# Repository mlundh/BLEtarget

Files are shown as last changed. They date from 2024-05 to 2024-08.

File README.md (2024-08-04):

# BLEtarget 
BLEtarget is an optical electronic scoring target with bluetooth connectivity developed for air guns. 

The project consists of both Hardware and firmware. The source is found in hw and fw respectively. 

## HW
The HW is developed in KiCad 7.0. It consists of a sensor array with support electronics as well as an STM32 with BLE capabilites. 

### Known bugs
BOM error - U8-U10 MCP604 populated with MCP6044 with 14kHz bandwidth, should be MCP604 with 2.8Mhz bandwidth.
BOM error - c32 and corresponding 10u caps should be changed to 10000PF for a shorter signal pulse.
Schematic error - add a jumper to select master/slave. 
Schematic update - add a small memory, fram.

## FW
The firmware developed in CubeIDE.

## SW
The user interface is called Bullseye and developed in Qt using widgets.

### Dependencies
qt6-base-dev-tools
qt6-serialport-dev
cmake

### Raspberry pi Zero 2W with Hyperpixel 4.0 Square
#### Increase swap file:
Edit /etc/dphys-swapfile to change CONF_SWAPSIZE=100 to CONF_SWAPSIZE=2048. After making the change, restart the Pi.
#### Enable Hyperpixel
Add one line in /boot/firmware/config.txt:
dtoverlay=vc4-kms-dpi-hyperpixel4sq
#### Convenience
Enable one-click open of files: 
In Accessories select File Manager
In File Manage select Preference.
Select "Open Files with One Click"
#### Add desktop shortcut
Add desktop shortcut by draging the application to the desktop. Also drag the updateBullseye.sh script to the desktop.

#### Start at bootup

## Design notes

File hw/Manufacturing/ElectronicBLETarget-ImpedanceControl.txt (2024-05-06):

Impedance control required

1) 50 Ohms (+-10%) Single-ended Microstrip
L1 (ref L2)
Trace width = 0.19mm

2) 90 Ohms (+-10%) Differential Microstrip (50 Ohms +-10% Single-Ended))
L1 (ref L2)
Trace width = 0.22mm
Trace spacing = 0.15mm

Confirm trace widths and spacing. Adjust stack-up as necessary.

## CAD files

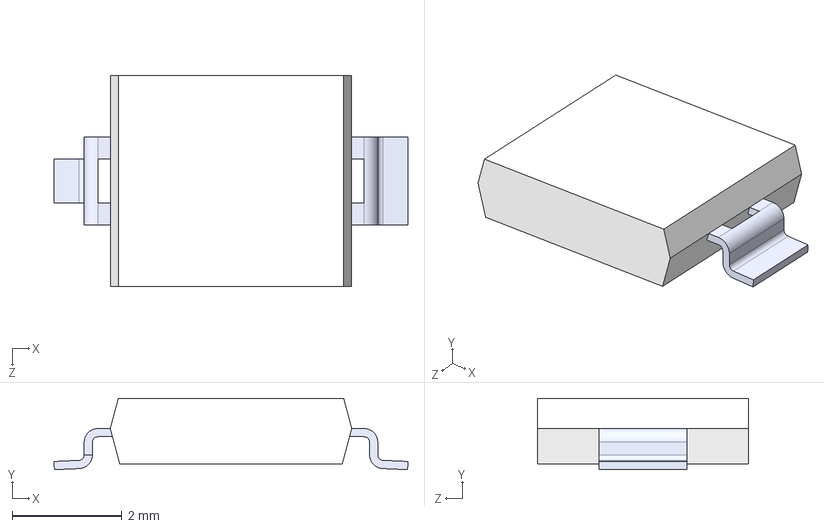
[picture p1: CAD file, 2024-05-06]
hw/BPW_34_S-Z.step
6.45 x 1.30 x 3.85 mm

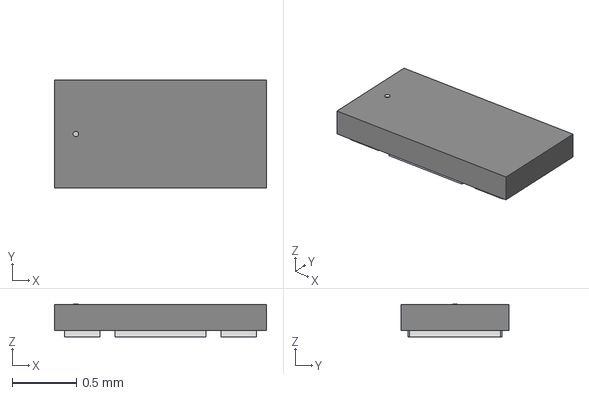
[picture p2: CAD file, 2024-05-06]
hw/DLF-4_1P6X0P8.step
1.65 x 0.838 x 0.257 mm

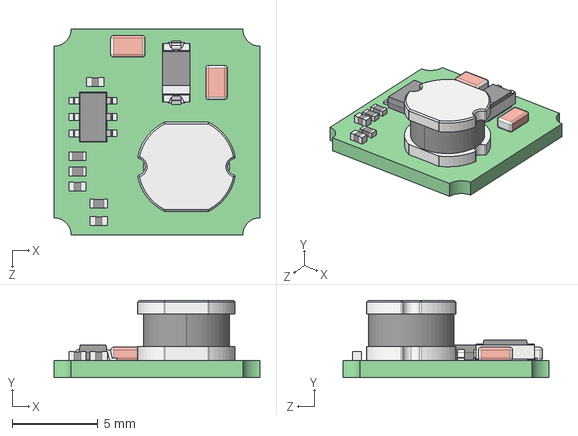
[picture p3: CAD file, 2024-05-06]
hw/CUI_PXO7809-500-M-TR.step
12.0 x 4.50 x 12.0 mm

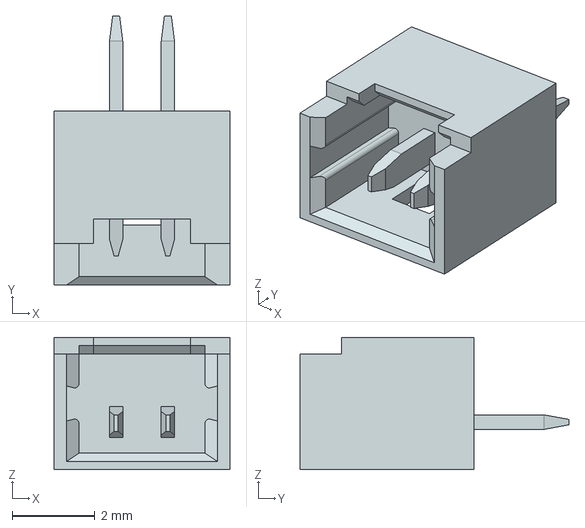
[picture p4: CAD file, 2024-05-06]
hw/530470210.stp
4.25 x 6.50 x 3.20 mm

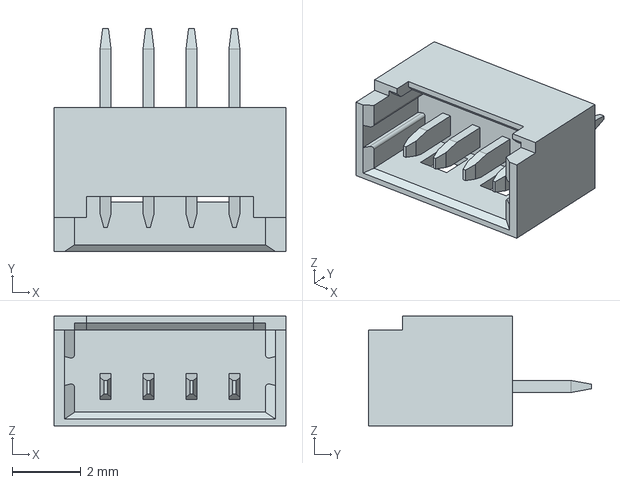
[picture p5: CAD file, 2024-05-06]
hw/530470410.stp
6.75 x 6.50 x 3.20 mm

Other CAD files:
hw/CUI_PXO7805-500-M-TR.step

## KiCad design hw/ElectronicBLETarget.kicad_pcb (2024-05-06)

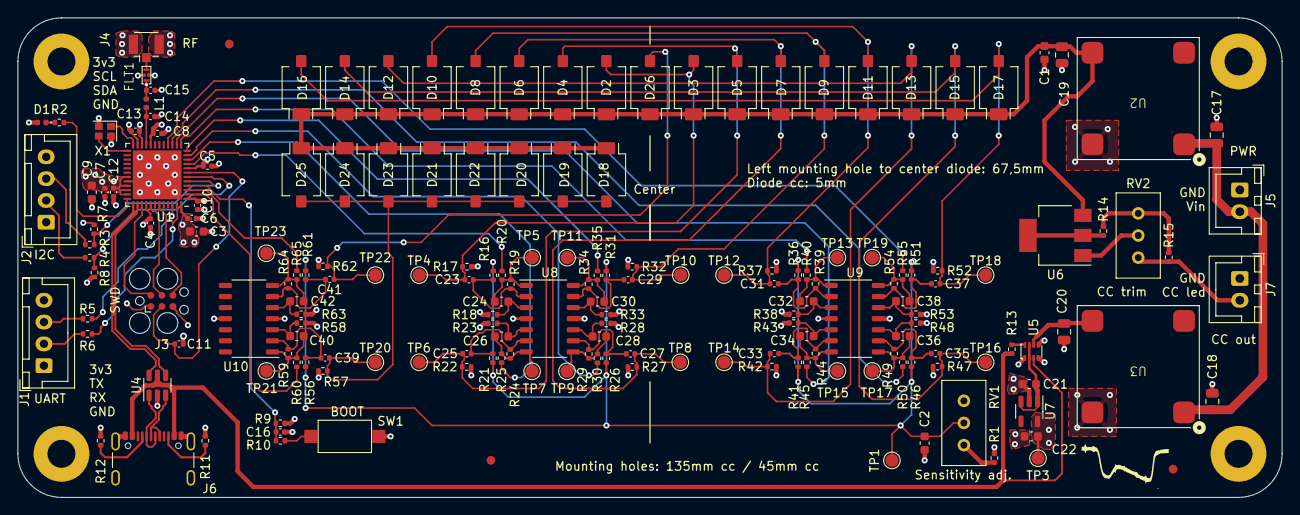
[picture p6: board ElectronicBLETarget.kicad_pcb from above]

Board: 4 copper layers, 145.0 x 55.0 mm, 185 parts (0 on the bottom side), 91 nets.

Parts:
C1, C2, C3, C9, C21, C22: 4u7; C_0603_1608Metric
C4, C5, C6, C7, C8, C10, C11, C12, C13, C16, C23, C25, C27, C29, C31, C33, C35, C37, C39, C41: 100n; C_0402_1005Metric
C14: 0p8; C_0402_1005Metric
C15: 0p3; C_0402_1005Metric
C17, C18: 10u; C_0805_2012Metric
C19, C20: 22u; C_0805_2012Metric
C24, C26, C28, C30, C32, C34, C36, C38, C40, C42: 10u; C_0603_1608Metric
D1: LED; LED_0402_1005Metric
D2, D3, D4, D5, D6, D7, D8, D9, D10, D11, D12, D13, D14, D15, D16, D17, D18, D19, D20, D21, D22, D23, D24, D25, D26: BPW34-SMD; Osram_BPW34S-SMD
FLT1: DLF162500LT-5028A1
FM1, FM2, FM3: Fiducial; Fiducial_1mm_Mask2mm
H1, H2, H3, H4: MountingHole_Pad; MountingHole_3.2mm_M3_Pad
J1, J2: Conn_01x04; JST_XH_B4B-XH-A_1x04_P2.50mm_Vertical
J3: Conn_ARM_SWD_TagConnect_TC2030; Tag-Connect_TC2030-IDC-FP_2x03_P1.27mm_Vertical
J4: Conn_Coaxial; U.FL_Hirose_U.FL-R-SMT-1_Vertical
J5, J7: Conn_01x02; JST_XH_B2B-XH-A_1x02_P2.50mm_Vertical
J6: USB_C_Receptacle_USB2.0; USB_C_Receptacle_GCT_USB4105-xx-A_16P_TopMnt_Horizontal
L1: 2n7; L_0402_1005Metric
R1: 20k; R_0402_1005Metric
R2, R3, R4, R5, R6, R10, R20, R25, R30, R35, R40, R45, R50, R55, R60, R65: 220R; R_0402_1005Metric
R7, R8, R13, R17, R22, R27, R32, R37, R42, R47, R52, R57, R62: 5.6k; R_0402_1005Metric
R9, R11, R12: 5k1; R_0402_1005Metric
R14: 10R; R_0402_1005Metric
R15: 22R; R_0402_1005Metric
R16, R21, R26, R31, R36, R41, R46, R51, R56, R61: 100K; R_0402_1005Metric
R18, R23, R28, R33, R38, R43, R48, R53, R58, R63: 150K; R_0402_1005Metric
R19, R24, R29, R34, R39, R44, R49, R54, R59, R64: 1M; R_0402_1005Metric
RV1, RV2: 3296W; Potentiometer_Bourns_3296W_Vertical
SW1: SW_Push; SW_SPST_CK_RS282G05A3
TP1, TP3, TP4, TP5, TP6, TP7, TP8, TP9, TP10, TP11, TP12, TP13, TP14, TP15, TP16, TP17, TP18, TP19, TP20, TP21, TP22, TP23: TestPoint; TestPoint_Pad_D1.5mm
U1: STM32WB55CEU6; QFN-48-1EP_7x7mm_P0.5mm_EP5.6x5.6mm
U2: PXO7809-500-M-TR; PXO7805-500-M-TR
U3: PXO7805-500-M-TR
U4: USBLC6-2SC6; SOT-23-6
U5: LM66200; SOT-583-8
U6: LM317_SOT-223; SOT-223-3_TabPin2
U7: MIC5365-3.3YD5; SOT-23-5
U8, U9, U10: MCP604; SOIC-14_3.9x8.7mm_P1.27mm
X1: 32MHz, NX2016SA-32M; Crystal_SMD_2016-4Pin_2.0x1.6mm

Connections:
+3V3: C3.1, C4.1, C5.1, C6.1, C7.1, C8.1, C9.1, C10.1, C12.1, C13.1, C22.1, D1.2 (A), J1.4, J2.4, J3.1 (VCC), R1.1, R7.1, R8.1, SW1.2, TP3.1, U1.1 (VBAT), U1.8 (VDDA), U1.20 (VDD), U1.23 (VDDRF), U1.31 (VFBSMPS), U1.33 (VLXSMPS), U1.34 (VDDSMPS), U1.35 (VDD), U1.40 (VDDUSB), U1.48 (VDD), U7.5 (VOUT), U8.4 (V+), U9.4 (V+), U10.4 (V+)
+5V: C21.1, U5.2 (VOUT), U5.7 (VOUT), U7.1 (VIN), U7.3 (EN)
+9V: C1.1, C19.1, D2.1 (K), D3.1 (K), D4.1 (K), D5.1 (K), D6.1 (K), D7.1 (K), D8.1 (K), D9.1 (K), D10.1 (K), D11.1 (K), D12.1 (K), D13.1 (K), D14.1 (K), D15.1 (K), D16.1 (K), D17.1 (K), D18.1 (K), D19.1 (K), D20.1 (K), D21.1 (K), D22.1 (K), D23.1 (K), D24.1 (K), D25.1 (K), D26.1 (K), U2.3 (+Vout), U6.3 (VI)
+BATT: C17.1, C18.1, J5.2, U2.1 (+Vin), U3.1 (+Vin)
/BOOT0: C16.1, R9.1, R10.1, U1.4 (PH3)
/HSE_IN: U1.25 (OSC_IN), X1.3
/HSE_OUT: U1.24 (OSC_OUT), X1.1
/I2C_SCL: R3.2, R7.2, U1.5 (PB8)
/I2C_SCLC: J2.3, R3.1
/I2C_SDA: R4.2, R8.2, U1.6 (PB9)
/I2C_SDAC: J2.2, R4.1
/LED: R2.2, U1.36 (PA10)
/Power/USB_CC1: J6.A5 (CC1), R12.1
/Power/USB_CC2: J6.B5 (CC2), R11.1
/Power/USB_FD+: J6.A6 (D+), J6.B6 (D+), U4.3 (I/O2)
/Power/USB_FD-: J6.A7 (D-), J6.B7 (D-), U4.1 (I/O1)
/RF: C14.1, L1.1, U1.21 (RF1)
/RF_ANT: FLT1.3 (OUT), J4.1 (In)
/RF_MATCH: C15.1, FLT1.1 (IN), L1.2
/SWD_CLK: J3.4 (SWCLK), U1.41 (PA14)
/SWD_DIO: J3.2 (SWDIO), U1.39 (PA13)
/SWD_NRST: C11.1, J3.3 (~RESET), U1.7 (NRST)
/SWD_TRC: J3.6 (SWO), U1.43 (PB3)
/SensorArrayGroup1/SensorChannel1/ch1_Minus: C23.2, R16.2, R19.1, U8.2 (-)
/SensorArrayGroup1/SensorChannel1/ch1_Output: C24.2, R19.2, R20.2, TP5.1, U8.1
/SensorArrayGroup1/SensorChannel1/ch1_Positive: C24.1, R18.2, U8.3 (+)
/SensorArrayGroup1/SensorChannel1/ch1_d: C23.1, D2.2 (A), D3.2 (A), R17.1, TP4.1
/SensorArrayGroup1/SensorChannel2/ch2_Minus: C25.2, R21.2, R24.1, U8.6 (-)
/SensorArrayGroup1/SensorChannel2/ch2_Positive: C26.1, R23.2, U8.5 (+)
/SensorArrayGroup1/SensorChannel2/ch2_d: C25.1, D4.2 (A), D5.2 (A), R22.1, TP6.1
/SensorArrayGroup1/SensorChannel2/ch2_output: C26.2, R24.2, R25.2, TP7.1, U8.7
/SensorArrayGroup1/SensorChannel3/ch3_D: C27.1, D6.2 (A), D7.2 (A), R27.1, TP8.1
/SensorArrayGroup1/SensorChannel3/ch3_Minus: C27.2, R26.2, R29.1, U8.9 (-)
/SensorArrayGroup1/SensorChannel3/ch3_output: C28.2, R29.2, R30.2, TP9.1, U8.8
/SensorArrayGroup1/SensorChannel3/ch3_positive: C28.1, R28.2, U8.10 (+)
/SensorArrayGroup1/SensorChannel4/ch4_D: C29.1, D8.2 (A), D9.2 (A), R32.1, TP10.1
/SensorArrayGroup1/SensorChannel4/ch4_negative: C29.2, R31.2, R34.1, U8.13 (-)
/SensorArrayGroup1/SensorChannel4/ch4_output: C30.2, R34.2, R35.2, TP11.1, U8.14
/SensorArrayGroup1/SensorChannel4/ch4_positive: C30.1, R33.2, U8.12 (+)
/SensorArrayGroup1/TrimPotCenterTap: C2.1, R16.1, R21.1, R26.1, R31.1, R36.1, R41.1, R46.1, R51.1, R56.1, R61.1, RV1.2, TP1.1
/SensorArrayGroup2/SensorChannel5/ch1_Minus: C31.2, R36.2, R39.1, U9.2 (-)
/SensorArrayGroup2/SensorChannel5/ch1_Output: C32.2, R39.2, R40.2, TP13.1, U9.1
/SensorArrayGroup2/SensorChannel5/ch1_Positive: C32.1, R38.2, U9.3 (+)
/SensorArrayGroup2/SensorChannel5/ch1_d: C31.1, D10.2 (A), D11.2 (A), R37.1, TP12.1
/SensorArrayGroup2/SensorChannel6/ch2_Minus: C33.2, R41.2, R44.1, U9.6 (-)
/SensorArrayGroup2/SensorChannel6/ch2_Positive: C34.1, R43.2, U9.5 (+)
/SensorArrayGroup2/SensorChannel6/ch2_d: C33.1, D12.2 (A), D13.2 (A), R42.1, TP14.1
/SensorArrayGroup2/SensorChannel6/ch2_output: C34.2, R44.2, R45.2, TP15.1, U9.7
/SensorArrayGroup2/SensorChannel7/ch3_D: C35.1, D14.2 (A), D15.2 (A), R47.1, TP16.1
/SensorArrayGroup2/SensorChannel7/ch3_Minus: C35.2, R46.2, R49.1, U9.9 (-)
/SensorArrayGroup2/SensorChannel7/ch3_output: C36.2, R49.2, R50.2, TP17.1, U9.8
/SensorArrayGroup2/SensorChannel7/ch3_positive: C36.1, R48.2, U9.10 (+)
/SensorArrayGroup2/SensorChannel8/ch4_D: C37.1, D16.2 (A), D17.2 (A), R52.1, TP18.1
/SensorArrayGroup2/SensorChannel8/ch4_negative: C37.2, R51.2, R54.1, U9.13 (-)
/SensorArrayGroup2/SensorChannel8/ch4_output: C38.2, R54.2, R55.2, TP19.1, U9.14
/SensorArrayGroup2/SensorChannel8/ch4_positive: C38.1, R53.2, U9.12 (+)
/SensorArrayGroup3/SensorBackRow/back_d: C39.1, D18.2 (A), D19.2 (A), D20.2 (A), D21.2 (A), D22.2 (A), D23.2 (A), D24.2 (A), D25.2 (A), R57.1, TP20.1
/SensorArrayGroup3/SensorBackRow/back_minus: C39.2, R56.2, R59.1, U10.2 (-)
/SensorArrayGroup3/SensorBackRow/back_output: C40.2, R59.2, R60.2, TP21.1, U10.1
/SensorArrayGroup3/SensorBackRow/back_positive: C40.1, R58.2, U10.3 (+)
/SensorArrayGroup3/SensorCenter/center_Minus: C41.2, R61.2, R64.1, U10.6 (-)
/SensorArrayGroup3/SensorCenter/center_d: C41.1, D26.2 (A), R62.1, TP22.1
/SensorArrayGroup3/SensorCenter/center_output: C42.2, R64.2, R65.2, TP23.1, U10.7
/SensorArrayGroup3/SensorCenter/center_positive: C42.1, R63.2, U10.5 (+)
/USART1_RX: R6.2, U1.47 (PB7)
/USART1_RXC: J1.2, R6.1
/USART1_TX: R5.2, U1.46 (PB6)
/USART1_TXC: J1.3, R5.1
/USB_D+: U1.38 (PA12), U4.4 (I/O2)
/USB_D-: U1.37 (PA11), U4.6 (I/O1)
/ch1: R20.1, U1.9 (PA0)
/ch2: R25.1, U1.10 (PA1)
/ch3: R30.1, U1.11 (PA2)
/ch4: R35.1, U1.12 (PA3)
/ch5: R40.1, U1.13 (PA4)
/ch6: R45.1, U1.14 (PA5)
/ch7: R50.1, U1.15 (PA6)
/ch8: R55.1, U1.16 (PA7)
/chCenter: R65.1, U1.3 (PC15)
/chSide: R60.1, U1.2 (PC14)
GND: C1.2, C2.2, C3.2, C4.2, C5.2, C6.2, C7.2, C8.2, C9.2, C10.2, C11.2, C12.2, C13.2, C14.2, C15.2, C16.2, C17.2, C18.2, C19.2, C20.2, C21.2, C22.2, FLT1.2 (GND), FLT1.4 (GND), H1.1, H2.1, H3.1, H4.1, J1.1, J2.1, J3.5 (GND), J4.2 (Ext), J5.1, J6.A1 (GND), J6.A12 (GND), J6.B1 (GND), J6.B12 (GND), J6.S1 (SHIELD), J7.1, R9.2, R11.2, R12.2, R17.2, R18.1, R22.2, R23.1, R27.2, R28.1, R32.2, R33.1, R37.2, R38.1, R42.2, R43.1, R47.2, R48.1, R52.2, R53.1, R57.2, R58.1, R62.2, R63.1, RV1.3, U1.22 (VSSRF), U1.32 (VSSSMPS), U1.49 (VSS), U2.4 (GND), U3.4 (GND), U4.2 (GND), U5.1 (GND), U5.4 (ON_), U5.5 (GND), U7.2 (GND), U8.11 (V-), U9.11 (V-), U10.11 (V-), X1.2, X1.4
unnamed: D1.1 (K), R2.1
unnamed: J7.2, R15.2, RV2.1
unnamed: R1.2, RV1.1
unnamed: R10.2, SW1.1
unnamed: R14.2, R15.1, RV2.3
unnamed: C20.1, U3.3 (+Vout), U5.6 (VIN2)
unnamed: J6.A4 (VBUS), J6.A9 (VBUS), J6.B4 (VBUS), J6.B9 (VBUS), R13.1, U4.5 (VBUS), U5.3 (VIN1)
unnamed: R13.2, U5.8 (ST)
unnamed: RV2.2, U6.1 (ADJ)
unnamed: R14.1, U6.2 (VO)

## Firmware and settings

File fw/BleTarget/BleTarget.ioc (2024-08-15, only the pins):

Mcu.UserName=STM32WB55CEUx
PA0.GPIO_Label=CH_1
PA0.Signal=GPXTI0
PA1.GPIO_Label=CH_2
PA1.Signal=GPXTI1
PA10.GPIO_Label=LED
PA10.Signal=GPIO_Output
PA11.Signal=USB_DM
PA12.Signal=USB_DP
PA13.Signal=SYS_JTMS-SWDIO
PA14.Signal=SYS_JTCK-SWCLK
PA2.GPIO_Label=CH_3
PA2.Signal=GPXTI2
PA3.GPIO_Label=CH_4
PA3.Signal=GPXTI3
PA4.GPIO_Label=CH_5
PA4.Signal=GPXTI4
PA5.GPIO_Label=CH_6
PA5.Signal=GPXTI5
PA6.GPIO_Label=CH_7
PA6.Signal=GPXTI6
PA7.GPIO_Label=CH_8
PA7.Signal=GPXTI7
PB3.Signal=SYS_JTDO-SWO
PB6.Signal=USART1_TX
PB7.Signal=USART1_RX
PB8.Signal=I2C1_SCL
PB9.Signal=I2C1_SDA
PC14-OSC32_IN.GPIO_Label=CH_B
PC14-OSC32_IN.Signal=GPXTI14
PC15-OSC32_OUT.GPIO_Label=CH_C
PC15-OSC32_OUT.Signal=GPXTI15
PH3-BOOT0.GPIO_Label=BOOT
PH3-BOOT0.Signal=GPIO_Input

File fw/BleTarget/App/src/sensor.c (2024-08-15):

/*
 * sensor.c
 *
 *  Created on: May 27, 2024
 *      Author: mlundh
 */

#include "sensor.h"


#define NR_CHANNELS (10)
#define BACK_CHANNEL (9)
#define TIME_PERIOD_S (0.000000015625)//(1/64 000 000)
#define DISTANCE_ROWS_M (0.01)
#define MM_BETWEEN_SENSORS (5)

const uint16_t pins[]={CH_C_Pin, CH_1_Pin, CH_2_Pin, CH_3_Pin, CH_4_Pin, CH_5_Pin, CH_6_Pin, CH_7_Pin, CH_8_Pin, CH_B_Pin};

typedef struct {
  TIM_TypeDef *timer; // 64MHz timer used to measure speed of pellet. Also used for timeout to report the hit.
  TIM_TypeDef *timerLockout; // .
  uint8_t buffer[NR_CHANNELS]; // position of the hit. 0 Center, 1-7 channel, 8 back.
  uint8_t newValue;
  uint32_t speed;
  invalidateFcn invalidateData;
} sensor_t;

sensor_t sensor = { TIM2, TIM16, { 0, 0, 0, 0, 0, 0, 0, 0, 0, 0 }, 0, 0, NULL };

/**
 * Disable all external interrupts to ensure we do not have concurrency issues.
 */
void disableExternalInterrupt();

/**
 * Re-enable the external interrupts. This should be done when all data from the external interrupts are handled.
 */
void enableExternalInterrupt();

void Sensor_init(uint8_t master, invalidateFcn invalidateCb)
{
  sensor.invalidateData = invalidateCb;

  if(master)
  {
    // Master should have a longer timeout so that the slave definitely have data. Timeout 20ms.
    sensor.timer->ARR = ((640000*2)-1);
  }
  else
  {
    // Slave has shorter timeout, 10ms.
    sensor.timer->ARR = (640000-1);
  }

}

// Multiple adjacent triggered photodiodes are allowed, this would represent a hit between the channels.
// It is not allowed to have a gap in between. This would be an error condition.

int Sensor_getPos()
{
  int returnValue = ERROR;
  if (sensor.newValue)
  {
    uint8_t first = NOT_USED;
    uint8_t last = NOT_USED;

    for (int i = 0; i < (BACK_CHANNEL); i++)
    {
      if (sensor.buffer[i])
      {
        if (first == NOT_USED)    // If no hit is registered yet, then register.
        {
          first = i;
          last = i;
        }
        else
        {
          if ((last + 1) == i) // If there is a hit registered, make sure the last hit was the adjacent sensor.
          {
            last = i;
          }
          else
          {
            // error condition!
            //ERROR_ENTRY("Gaps between triggered sensors.");
            return returnValue;
          }
        }
      }
    }

    if (first != NOT_USED) // If there is a valid hit
    {
      returnValue = ((first * MM_BETWEEN_SENSORS) + (last * MM_BETWEEN_SENSORS))
          / 2; // integer values, scale to 5mm between channels.
    }

    if (sensor.buffer[BACK_CHANNEL]) // Left is negative.
    {
      returnValue = -(returnValue);
    }
  }
  //LOG_DBG_ENTRY("Position = %d",returnValue);
  return returnValue;
}

float Sensor_getSpeed()
{
  float returnValue = SPEED_ERROR;
  if (sensor.speed)
  {
    returnValue = DISTANCE_ROWS_M / (((float) sensor.speed) * TIME_PERIOD_S);
    //LOG_DBG_ENTRY("Speed = %d",(int)returnValue);
    if(returnValue < 2 || returnValue > 500)
    {
      // Error. Only support speed values between 2 and 500 m/s.
      returnValue = SPEED_ERROR;
    }
  }
  return returnValue;
}

unsigned int Sensor_newValue()
{
  return sensor.newValue;
}

void Sensor_clear()
{
  memset(sensor.buffer, 0, NR_CHANNELS); // clean up and get ready for next hit.
  sensor.speed = 0;
  sensor.newValue = 0;
}

void HAL_GPIO_EXTI_Callback(uint16_t GPIO_Pin)
{
  if (GPIO_Pin == CH_C_Pin)
  {
    sensor.buffer[0] = 1;
  }
  if (GPIO_Pin == CH_1_Pin)
  {
    sensor.buffer[1] = 1;
  }
  if (GPIO_Pin == CH_2_Pin)
  {
    sensor.buffer[2] = 1;
  }
  if (GPIO_Pin == CH_3_Pin)
  {
    sensor.buffer[3] = 1;
  }
  if (GPIO_Pin == CH_4_Pin)
  {
    sensor.buffer[4] = 1;
  }
  if (GPIO_Pin == CH_5_Pin)
  {
    sensor.buffer[5] = 1;
  }
  if (GPIO_Pin == CH_6_Pin)
  {
    sensor.buffer[6] = 1;
  }
  if (GPIO_Pin == CH_7_Pin)
  {
    sensor.buffer[7] = 1;
  }
  if (GPIO_Pin == CH_8_Pin)
  {
    sensor.buffer[8] = 1;
  }

  if (GPIO_Pin == CH_B_Pin) // it is the back row.
  {
    sensor.buffer[BACK_CHANNEL] = 1;

    if (!LL_TIM_IsEnabledCounter(sensor.timer)) // If back detector was triggered, and the timer was not already going, start it.
    {
      LL_TIM_SetCounter(sensor.timer, 0);
      LL_TIM_ClearFlag_UPDATE(sensor.timer);
      LL_TIM_EnableIT_UPDATE(sensor.timer);
      LL_TIM_EnableCounter(sensor.timer); // measure time between back row and other rows.
    }
    else
    {
      //ERROR_ENTRY("Back row hit after scoring row."); // Todo write error to!
    }
  }
  else // it is not the back row.
  {
    if (!LL_TIM_IsEnabledCounter(sensor.timer)) //  The timer is not enabled. We should start the timer as it is also used to ensure enough time has passed before registering a new value.
    {
      LL_TIM_SetCounter(sensor.timer, 0);
      LL_TIM_ClearFlag_UPDATE(sensor.timer);
      LL_TIM_EnableIT_UPDATE(sensor.timer);
      LL_TIM_EnableCounter(sensor.timer); // measure time between back row and other rowes.
    }
    else // The timer is started, lets measure the time!
    {
      if ((sensor.buffer[BACK_CHANNEL] == 1) && (!sensor.speed)) // only take a measurement if the back row was triggered, and if no other speed was registered.
      {
        sensor.speed = LL_TIM_GetCounter(sensor.timer); //
      }
    }
  }
}

void timer2UpdateISR()
{
  // Stop the timer then enable the flag for new value.
  LL_TIM_DisableCounter(sensor.timer);
  LL_TIM_SetCounter(sensor.timer, 0);
  LL_TIM_DisableIT_UPDATE(sensor.timer);
  LL_TIM_ClearFlag_UPDATE(sensor.timer);

  sensor.newValue = 1;

  // Lockout timer, disable the external interrupts for 0.5s.
  disableExternalInterrupt();
  LL_TIM_SetCounter(sensor.timerLockout, 0);
  LL_TIM_ClearFlag_UPDATE(sensor.timerLockout);
  LL_TIM_EnableIT_UPDATE(sensor.timerLockout);
  LL_TIM_EnableCounter(sensor.timerLockout);
}

void timer16UpdateISR()
{
  // Stop the lockout timer and enable external interrupts.
  LL_TIM_DisableCounter(sensor.timerLockout);
  LL_TIM_SetCounter(sensor.timerLockout, 0);
  LL_TIM_DisableIT_UPDATE(sensor.timerLockout);
  LL_TIM_ClearFlag_UPDATE(sensor.timerLockout);
  if(sensor.invalidateData)
  {
    sensor.invalidateData();
  }
  enableExternalInterrupt();
}

void disableExternalInterrupt()
{
  HAL_NVIC_DisableIRQ(EXTI0_IRQn);

  HAL_NVIC_DisableIRQ(EXTI1_IRQn);

  HAL_NVIC_DisableIRQ(EXTI2_IRQn);

  HAL_NVIC_DisableIRQ(EXTI3_IRQn);

  HAL_NVIC_DisableIRQ(EXTI4_IRQn);

  HAL_NVIC_DisableIRQ(EXTI9_5_IRQn);

  HAL_NVIC_DisableIRQ(EXTI15_10_IRQn);
}

void clearAllExtInterrupts()
{
  for (int i = 0; i < NR_CHANNELS; i++)
  {
    if (__HAL_GPIO_EXTI_GET_IT(pins[i]) != 0x00u)
    {
      __HAL_GPIO_EXTI_CLEAR_IT(pins[i]);
    }
  }
}
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

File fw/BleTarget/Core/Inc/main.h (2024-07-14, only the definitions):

#define LOG_DBG_LENGTH_MAX (80)
#define LOG_LENGTH_MAX (80)
#define ERROR_LENGTH_MAX (80)
#define CH_B_Pin GPIO_PIN_14
#define CH_B_GPIO_Port GPIOC
#define CH_B_EXTI_IRQn EXTI15_10_IRQn
#define CH_C_Pin GPIO_PIN_15
#define CH_C_GPIO_Port GPIOC
#define CH_C_EXTI_IRQn EXTI15_10_IRQn
#define BOOT_Pin GPIO_PIN_3
#define BOOT_GPIO_Port GPIOH
#define CH_1_Pin GPIO_PIN_0
#define CH_1_GPIO_Port GPIOA
#define CH_1_EXTI_IRQn EXTI0_IRQn
#define CH_2_Pin GPIO_PIN_1
#define CH_2_GPIO_Port GPIOA
#define CH_2_EXTI_IRQn EXTI1_IRQn
#define CH_3_Pin GPIO_PIN_2
#define CH_3_GPIO_Port GPIOA
#define CH_3_EXTI_IRQn EXTI2_IRQn
#define CH_4_Pin GPIO_PIN_3
#define CH_4_GPIO_Port GPIOA
#define CH_4_EXTI_IRQn EXTI3_IRQn
#define CH_5_Pin GPIO_PIN_4
#define CH_5_GPIO_Port GPIOA
#define CH_5_EXTI_IRQn EXTI4_IRQn
#define CH_6_Pin GPIO_PIN_5
#define CH_6_GPIO_Port GPIOA
#define CH_6_EXTI_IRQn EXTI9_5_IRQn
#define CH_7_Pin GPIO_PIN_6
#define CH_7_GPIO_Port GPIOA
#define CH_7_EXTI_IRQn EXTI9_5_IRQn
#define CH_8_Pin GPIO_PIN_7
#define CH_8_GPIO_Port GPIOA
#define CH_8_EXTI_IRQn EXTI9_5_IRQn
#define LED_Pin GPIO_PIN_10
#define LED_GPIO_Port GPIOA

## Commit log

2024-05-06 HW as sent for manufacturing at PCBway.
    [530470210.stp, 530470410.stp, BPW_34_S-Z.step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]
2024-07-14 Initial firmware push. Sensor detects rising edges and computes position and velocity.
2024-07-24 Update gitignore to ignore metadatafiles from eclipse and backups from kicad.
2024-07-26 QT application talks to BLE target via UART.
2024-07-27 Feature: Two cards communicate over i2c, and the master transmitts the complete data to the SW application.
2024-08-02 Clear speed on button.
2024-08-15 Send both speed measues (x and Y) to Bullseye. Show both of these on the GUI.
    Add button to save scores to file. Naive first solution, saves all registered hits since the program was started.

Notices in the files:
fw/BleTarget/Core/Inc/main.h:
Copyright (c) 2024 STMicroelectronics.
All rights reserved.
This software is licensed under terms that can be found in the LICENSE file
